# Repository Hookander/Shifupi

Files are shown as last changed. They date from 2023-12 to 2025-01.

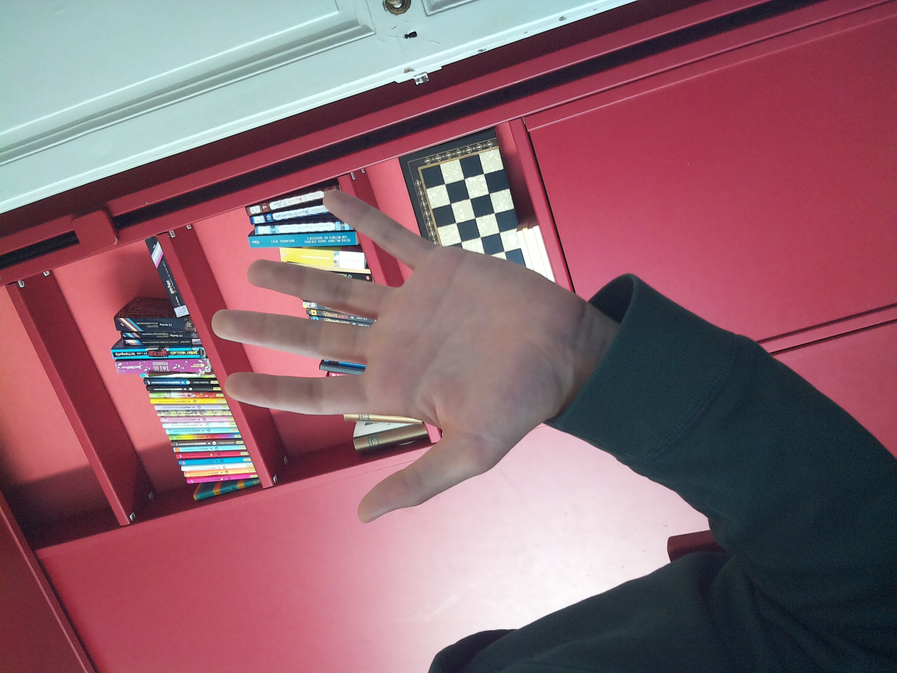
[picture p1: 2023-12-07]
Fichier Pi 081023/shifumi/test.jpg

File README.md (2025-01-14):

# Shifupi

Shifupi is a 3D-printed robotic hand controlled by a Raspberry Pi to play Rock-Paper-Scissors. 
It has a camera connected to a hand-mand AI to detect which symbol the player played and therefore determine who won.
For now I still have to improve the structure but it's working just fine ^^
## Contributing

Pull requests are welcome. For major changes, please open an issue first
to discuss what you would like to change.

Please make sure to update tests as appropriate.

## License

[MIT](https://choosealicense.com/licenses/mit/)

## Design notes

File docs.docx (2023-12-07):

SHIFUPI

Idée principale : le pi est connecté à une caméra et peut contrôler 5 stepper motors, chacun articulant un doigt d’une main imprimée en 3D. Alors le pi est capable d’effectuer les 3 gestes du pierre-feuille-ciseaux avec les moteurs. La caméra sert à voir la main du jouer, et reconnaitre le coup joué. Ainsi le pi peut déterminer qui a gagné entre lui et le joueur humain.

Pour reconnaitre le geste, on utilise le module MédiaPipe qui permet sur une image/vidéo/live de tracker 21 points sur une mains, les landmarks. Le pi va apprendre à associer les positions relatives de ces points avec les gestes du shifumi avec un réseau de neurones. Le fait qu’in n’y ait que 3 gestes à distinguer simplifie grandement la tâche : pas besoin de 21 points pour distinguer une pierre d’une feuille..

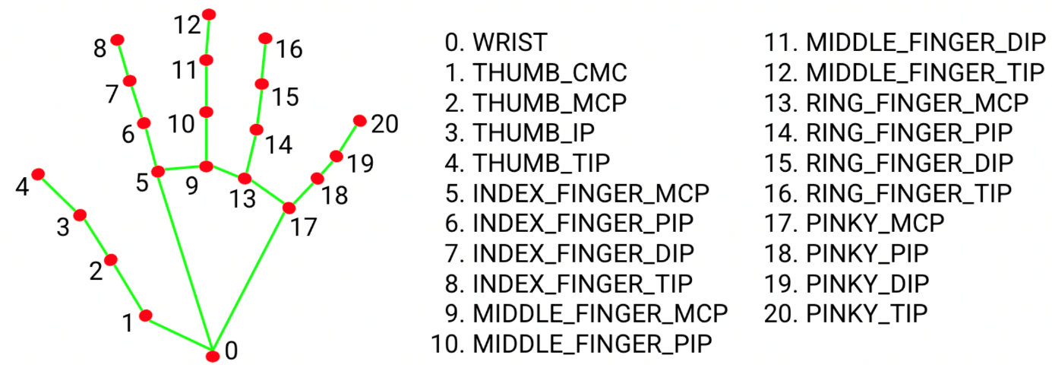
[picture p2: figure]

On va donc en sélectionner 4/5/6, enregistrer des vidéos témoins de chaque geste, récupérer les positions relatives des landmarks et envoyer tout ca dans un réseau de neurones qui tournera sur le pc principal pour apprendre (pi pas assez puissant). Il ne restera qu’à récupérer les coefficients du réseau.

Premier essai : on va prendre les landmarks 8, 12, 16, 20. (on ne prend pas le pouce car il y a deux types de ciseaux : avec pouce tendu ou non, donc on simplifie encore pour le réseau ici).

On doit prendre les positions relatives par rapport au bas de la main pour simplifier la tache au réseau. En effet il n’y aura alors aucune différence entre une pierre ou une pierre décalée de 2 cm devant la caméra.

IMPORTANT : il faut activer legacy camera dans « raspi-config » pour que le code python fonctionne mais on ne peut alors plus prendre de photo dans le terminal sans le désactiver à nouveau (nécessite un reboot à chaque fois).

Pour les moteurs : exemple de branchement

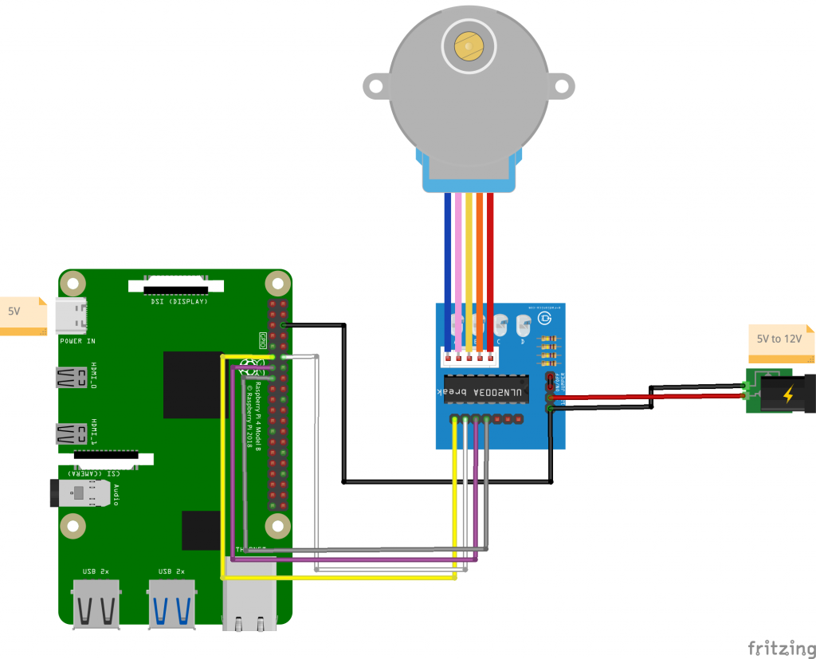
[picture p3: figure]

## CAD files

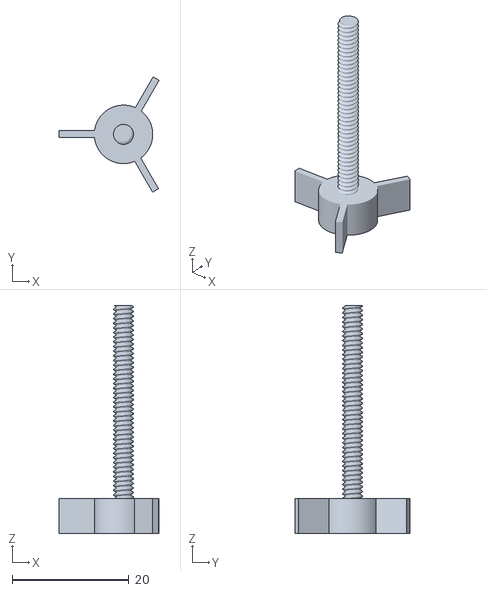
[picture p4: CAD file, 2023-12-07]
3D/Vis Boite.stl
17.1 x 19.7 x 39.0

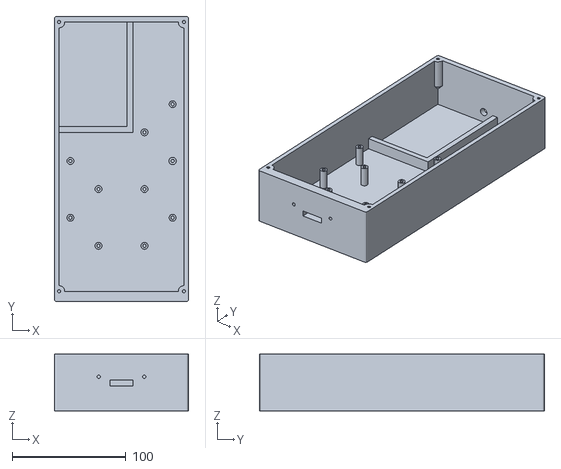
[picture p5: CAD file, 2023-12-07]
3D/Boite RdC v4.stl
118.0 x 251.0 x 50.0

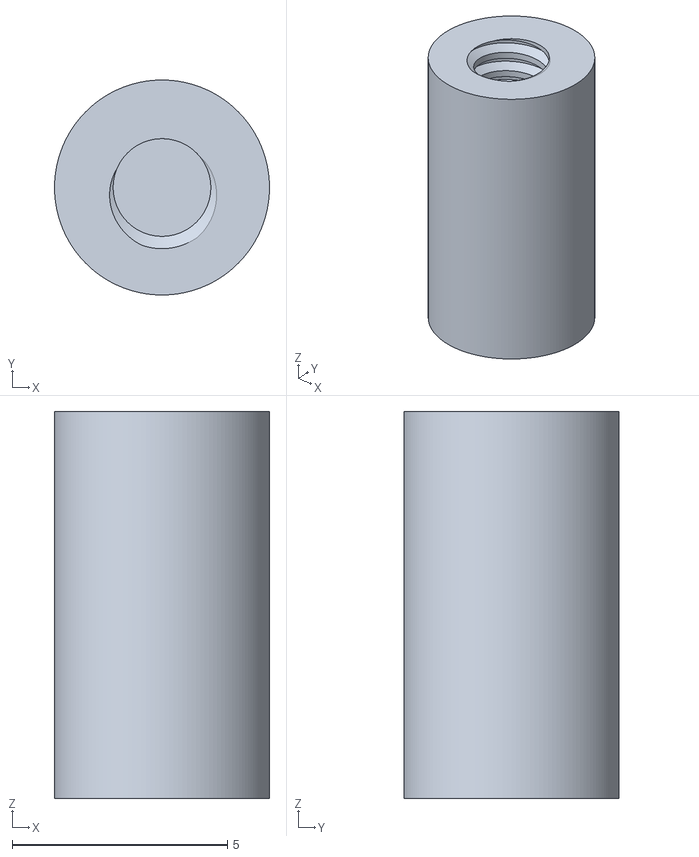
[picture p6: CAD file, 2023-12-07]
3D/ULN Holder Top v2.stl
5.00 x 5.00 x 9.00

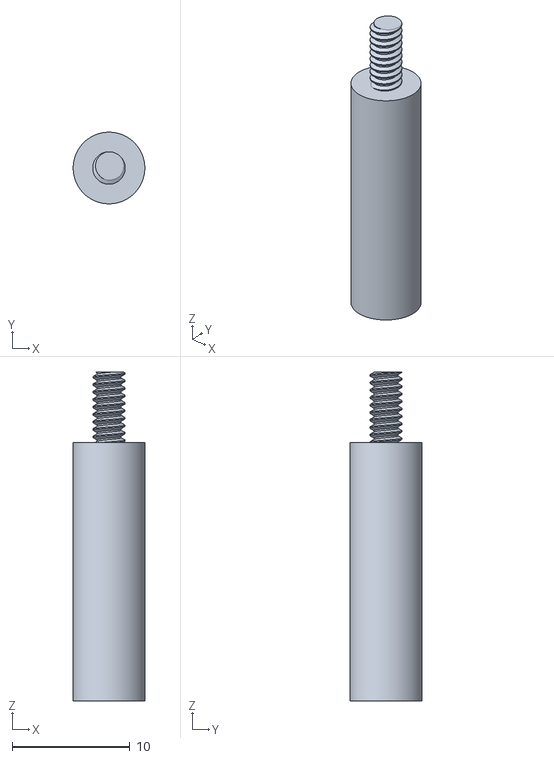
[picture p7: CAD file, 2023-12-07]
3D/TestMotorHolderv3.stl
6.10 x 6.10 x 28.0

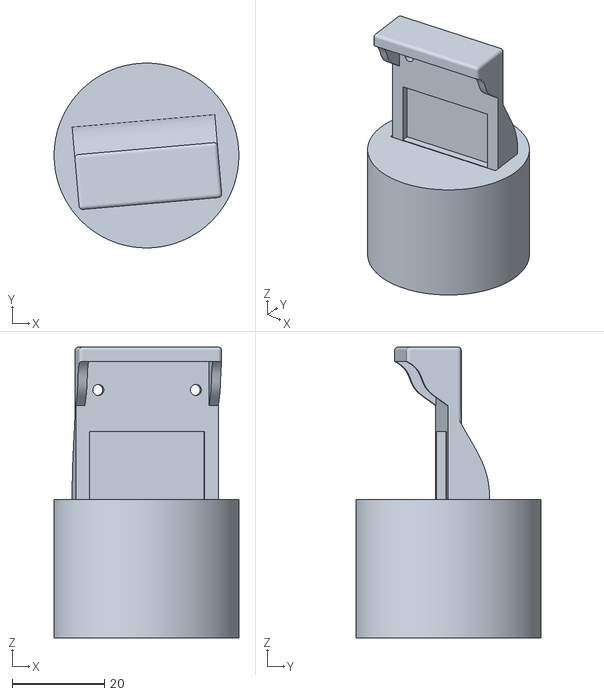
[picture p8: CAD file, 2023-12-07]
3D/Camera Holder v3.stl
40.0 x 40.0 x 63.0

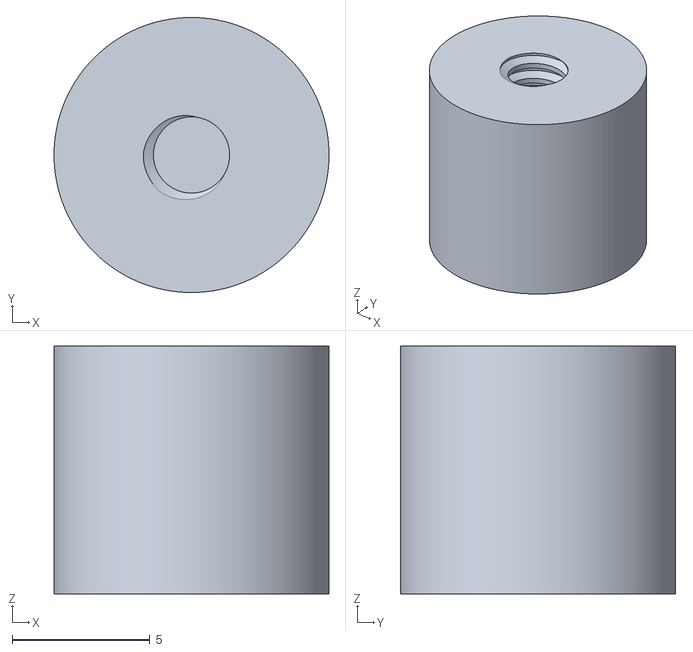
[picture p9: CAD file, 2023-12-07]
3D/TestMotorHolderTopv4.stl
10.00 x 10.00 x 9.00

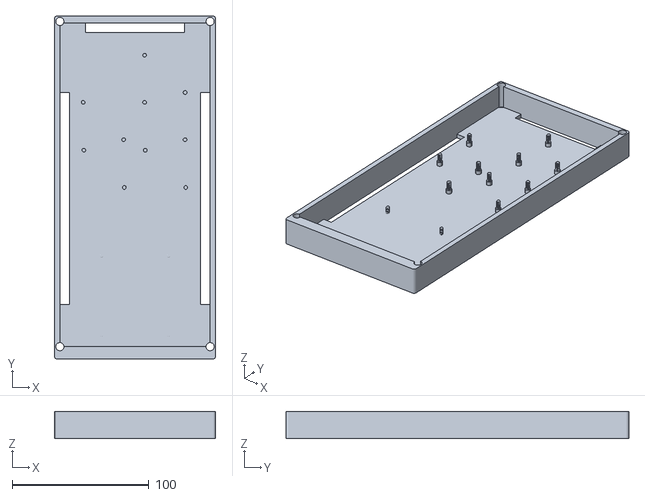
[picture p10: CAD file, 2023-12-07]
3D/Pi Holder.stl
118.0 x 251.0 x 20.0

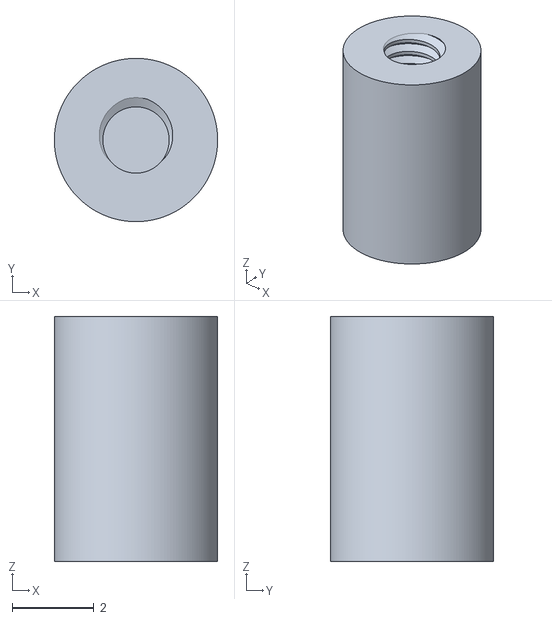
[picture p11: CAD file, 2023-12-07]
3D/TestMotorHolderTop.stl
4.00 x 4.00 x 6.00

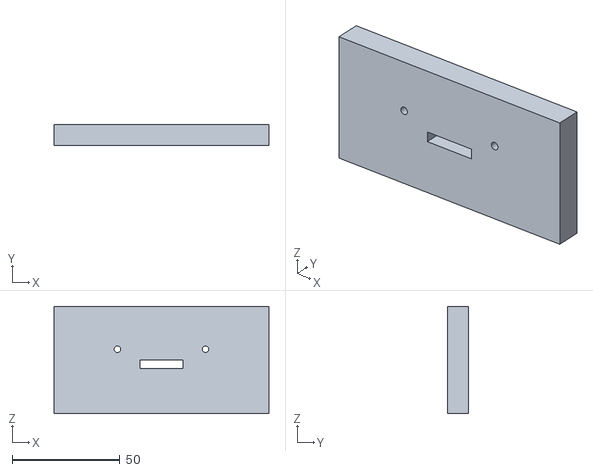
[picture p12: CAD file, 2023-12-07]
3D/Box v1.stl
100.0 x 10.0 x 50.0

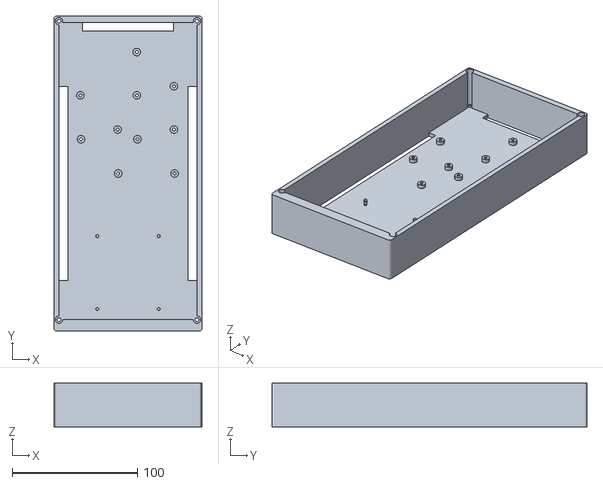
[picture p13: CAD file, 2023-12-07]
3D/Pi Holder v2.stl
118.0 x 251.0 x 35.0

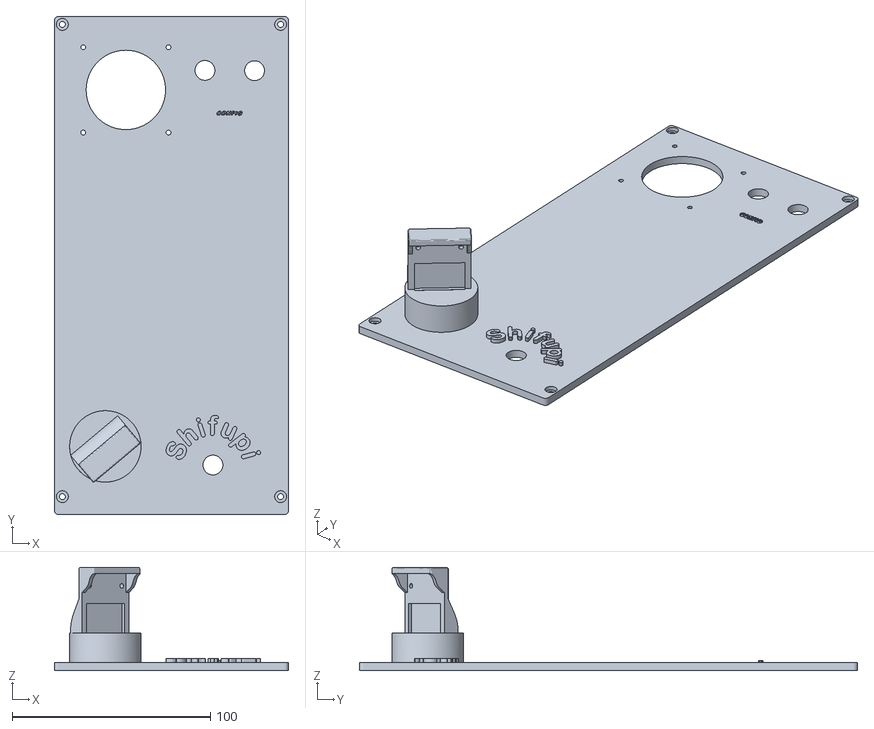
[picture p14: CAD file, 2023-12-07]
3D/Top v2.stl
118.0 x 251.0 x 52.0

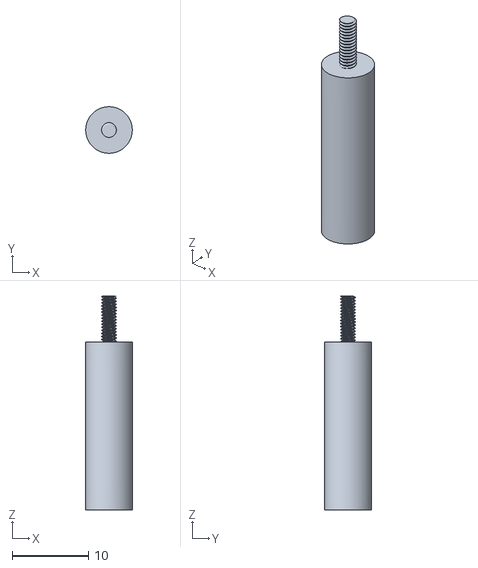
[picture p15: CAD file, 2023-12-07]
3D/TestMotorHolderv2.stl
6.10 x 6.10 x 28.0

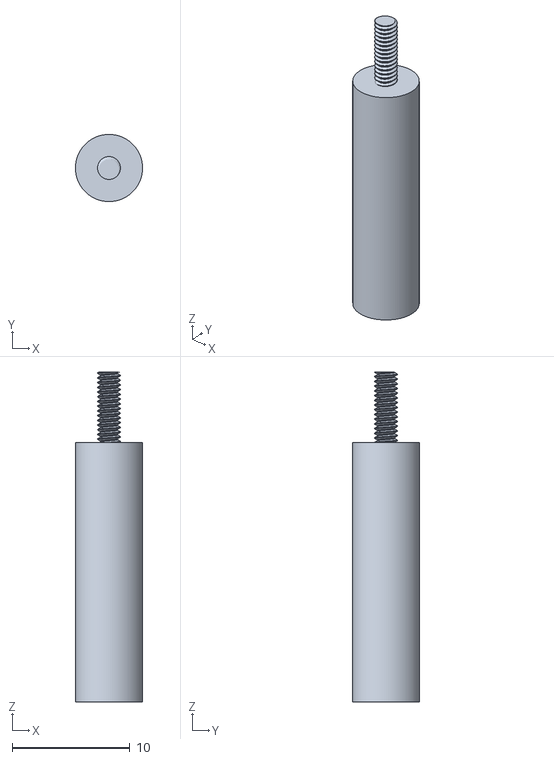
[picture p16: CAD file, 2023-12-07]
3D/TestMotorHolder.stl
5.70 x 5.70 x 28.0

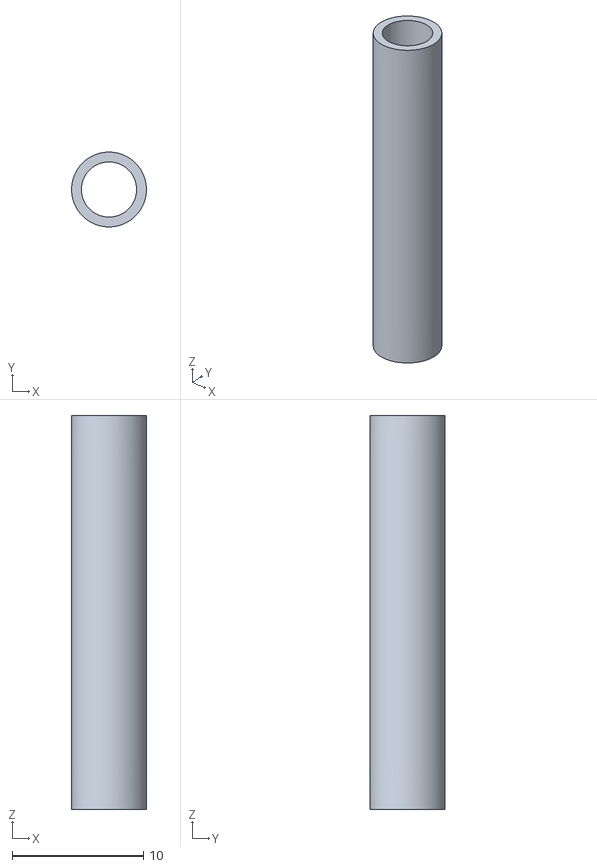
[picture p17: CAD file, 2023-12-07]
3D/Test Support Moteur.stl
5.70 x 5.70 x 30.0

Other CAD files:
3D/Boite RdC.stl
3D/Corps3.stl
3D/TestMotorHolderTopv3.stl
3D/Pi Holder Top v1.stl
3D/Boite RdC v2.stl
3D/Boite RdC v3.stl
3D/Camera Holder v1.stl
3D/Camera Holder v2.stl
3D/Motor Wheel v8.stl
3D/MotorWheel v2.stl
3D/MotorWheel v3.stl
3D/MotorWheel v5.stl
3D/MotorWheel v6.stl
3D/MotorWheel v7.stl
3D/Pi Holder v1.stl
3D/Test ULN Holder v2.stl
3D/Test ULN Holder.stl
3D/TestMotorHolderTopv2.stl
3D/TestMotorHolderv4.stl
3D/Top v1.stl
3D/ULN holder top v1.stl
3D/URN holder test.stl
3D/test HP holder.stl

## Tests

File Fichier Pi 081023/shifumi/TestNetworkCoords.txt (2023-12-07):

0
0 337.70938873291016 417.9077339172363
8 324.86968994140625 276.6591453552246
12 297.6041603088379 295.26835441589355
16 273.57954025268555 316.463098526001
20 253.7700080871582 339.721155166626
1
0 342.58949279785156 429.89161491394043
8 327.08812713623047 283.43713760375977
12 298.7298583984375 301.16180419921875
16 275.7464408874512 325.29290199279785
20 257.7950859069824 349.77965354919434
2
0 346.82464599609375 443.9021301269531
8 331.9491958618164 294.37737464904785
12 303.0389213562012 315.21549224853516
16 280.0699806213379 338.0496883392334
20 259.84243392944336 362.26996421813965
3
0 349.27947998046875 448.37682723999023
8 331.9996643066406 302.72400856018066
12 303.73836517333984 322.81405448913574
16 281.1668586730957 345.95598220825195
20 262.61714935302734 371.48529052734375
4
0 351.7687225341797 454.3619441986084
8 334.43607330322266 310.0864791870117
12 304.96437072753906 329.80530738830566
16 282.0871925354004 353.12315940856934
20 262.7654266357422 381.17237091064453
5
0 350.05619049072266 457.37935066223145
8 332.7268600463867 314.2350482940674
12 303.7798309326172 333.4299373626709
16 281.84988021850586 357.8453063964844
20 261.4082145690918 384.9485492706299
6
0 345.84300994873047 466.0671043395996
8 322.44678497314453 324.53516006469727
12 294.5882225036621 346.54051780700684
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

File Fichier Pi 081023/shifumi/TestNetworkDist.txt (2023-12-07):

0
8 141.83096148520258
12 129.0304101807841
16 120.0152136845877
20 114.71251335367835
1
8 147.2725577342008
12 135.9964400133266
16 124.13252729827134
20 116.65340883866551
2
8 150.26287471436427
12 135.9317492372241
16 125.14361662393421
20 119.2883721364819
3
8 146.67425002056413
12 133.56647423196745
16 123.00145803354104
20 115.85623836381117
4
8 145.31287119066863
12 133.06014851011344
16 122.90161581010489
20 115.2315074919141
5
8 144.18944827593094
12 132.30630563679244
16 120.66120639561666
20 114.47569447368151
6
8 143.45269113314777
12 130.05252063751985
16 118.76180527354165
20 116.28476375869867
7
8 146.27969362475437
12 127.99580165969333
16 114.93893911145571
20 112.48984473194751
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

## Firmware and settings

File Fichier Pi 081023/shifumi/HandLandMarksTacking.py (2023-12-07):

import cv2
import mediapipe as mp
import numpy as np
mp_drawing = mp.solutions.drawing_utils
mp_hands = mp.solutions.hands

filecords = open("shifumi/scissorsCoords.txt", "w") #avec les coordonnées directement
filedists = open("shifumi/scissorsDistances.txt", "w") #avec les distances calculées directement

filecords = open("shifumi/TestNetworkCoords.txt", "w")
filedists = open("shifumi/TestNetworkDist.txt", "w")
cptImg = 0
# For webcam input:
cap = cv2.VideoCapture(0)
with mp_hands.Hands(
    min_detection_confidence=0.5,
    min_tracking_confidence=0.5) as hands:
  while cap.isOpened():
    success, image = cap.read()
    if not success:
      print("Ignoring empty camera frame.")
      # If loading a video, use 'break' instead of 'continue'.
      continue

    # Flip the image horizontally for a later selfie-view display, and convert
    # the BGR image to RGB.
    image = cv2.cvtColor(cv2.flip(image, 1), cv2.COLOR_BGR2RGB)
    # To improve performance, optionally mark the image as not writeable to
    # pass by reference.
    image.flags.writeable = False
    results = hands.process(image)
    image_height, image_width, _ = image.shape
    # Draw the hand annotations on the image.
    image.flags.writeable = True
    image = cv2.cvtColor(image, cv2.COLOR_RGB2BGR)
    
    filecords.write(str(cptImg) + "\n")
    filedists.write(str(cptImg) + "\n")
    print(cptImg)
    if results.multi_hand_landmarks:
      for hand_landmarks in results.multi_hand_landmarks:
        # Here is How to Get All the Coordinates
        cx0, cy0 = hand_landmarks.landmark[0].x * image_width, hand_landmarks.landmark[0].y * image_height
        for ids, landmrk in enumerate(hand_landmarks.landmark):
            # print(ids, landmrk)
            cx, cy = landmrk.x * image_width, landmrk.y*image_height
            #print(cx, cy)
            """premier essai : landmarks 8, 12, 16, 20 (position relative par rapport au numéro 0)
                Donc on les enregistre dans un fichier .txt
            """
            wantedLM = [0, 8, 12,  16, 20] #Ceux que l'on tracke
            
            if ids in wantedLM:
              filecords.write(str(ids) + " " + str(cx) + " " +str(cy))
              filecords.write("\n")
              
              if ids != 0:
                dist = np.sqrt( (cx - cx0)**2 + (cy - cy0)**2)
                filedists.write(str(ids) + " " + str(dist) + ("\n"))
            #print (ids, cx, cy)
        mp_drawing.draw_landmarks(
            image, hand_landmarks, mp_hands.HAND_CONNECTIONS)
    # BM peut pas marcher s'il n'y a pas d'écran :)
    # cv2.imshow('MediaPipe Hands', image)
    if cv2.waitKey(5) & 0xFF == 27:
      break
    cptImg += 1
cap.release()
file.close()

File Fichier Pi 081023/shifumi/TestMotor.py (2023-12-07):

import RPi.GPIO as GPIO
import time

in1_middle = 17
in2_middle = 18
in3_middle = 27
in4_middle = 22

in1_ring = 23
in2_ring = 24
in3_ring = 25
in4_ring = 21


# careful lowering this, at some point you run into the mechanical limitation of how quick your motor can move
step_sleep = 0.0008

step_count_middle = 4096 # 5.625*(1/64) per step, 4096 steps is 360°
step_count_ring = 4096 # 5.625*(1/64) per step, 4096 steps is 360°

direction = False # True for clockwise, False for counter-clockwise
#direction_ring = False # True for clockwise, False for counter-clockwise


# defining stepper motor sequence (found in documentation http://www.4tronix.co.uk/arduino/Stepper-Motors.php)
step_sequence = [[1,0,0,1],
                 [1,0,0,0],
                 [1,1,0,0],
                 [0,1,0,0],
                 [0,1,1,0],
                 [0,0,1,0],
                 [0,0,1,1],
                 [0,0,0,1]]


# setting up
GPIO.setmode( GPIO.BCM )
GPIO.setup( in1_middle, GPIO.OUT )
GPIO.setup( in2_middle, GPIO.OUT )
GPIO.setup( in3_middle, GPIO.OUT )
GPIO.setup( in4_middle, GPIO.OUT )

GPIO.setup( in1_ring, GPIO.OUT )
GPIO.setup( in2_ring, GPIO.OUT )
GPIO.setup( in3_ring, GPIO.OUT )
GPIO.setup( in4_ring, GPIO.OUT )

# initializing
GPIO.output( in1_middle, GPIO.LOW )
GPIO.output( in2_middle, GPIO.LOW )
GPIO.output( in3_middle, GPIO.LOW )
GPIO.output( in4_middle, GPIO.LOW )

GPIO.output( in1_ring, GPIO.LOW )
GPIO.output( in2_ring, GPIO.LOW )
GPIO.output( in3_ring, GPIO.LOW )
GPIO.output( in4_ring, GPIO.LOW )

motor_pins_middle = [in1_middle,in2_middle,in3_middle,in4_middle]
motor_step_counter = 0

motor_pins_ring = [in1_ring,in2_ring,in3_ring,in4_ring]
#motor_step_counter_ring = 0 ;

def cleanup():
    GPIO.output( in1_middle, GPIO.LOW )
    GPIO.output( in2_middle, GPIO.LOW )
    GPIO.output( in3_middle, GPIO.LOW )
    GPIO.output( in4_middle, GPIO.LOW )
    
    GPIO.output( in1_ring, GPIO.LOW )
    GPIO.output( in2_ring, GPIO.LOW )
    GPIO.output( in3_ring, GPIO.LOW )
    GPIO.output( in4_ring, GPIO.LOW )
    GPIO.cleanup()

# the meat
try:
    i = 0
    for i in range(step_count_middle):
        for pin in range(0, len(motor_pins_middle)):
            GPIO.output( motor_pins_middle[pin], step_sequence[motor_step_counter][pin] )
            GPIO.output( motor_pins_ring[pin], step_sequence[motor_step_counter][pin] )    
        if direction==True:
            motor_step_counter = (motor_step_counter - 1) % 8
        elif direction==False:
            motor_step_counter = (motor_step_counter+ 1) % 8
        else: # defensive programming
            print( "uh oh... direction should *always* be either True or False" )
            cleanup()
            exit( 1 )
        time.sleep( step_sleep )

except KeyboardInterrupt:
    cleanup()
    exit( 1 )

cleanup()
exit( 0 )

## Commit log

2023-08-28 Detecte just la main
2023-08-29 Commence à bien lire les fichiers
2023-08-29 marche mais la descente se passe mal
2023-12-07 Start Commit, clean up coming
    [Boite RdC v2.stl, Boite RdC v3.stl, Boite RdC v4.stl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]
